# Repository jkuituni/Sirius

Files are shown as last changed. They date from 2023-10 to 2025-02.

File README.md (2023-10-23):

A very simple 6502 based single board computer with just about as much chips as is needed as minimum.

- 6502 CPU
- 8kB EPROM for Firmware
- Up to 48kB RAM comprised from maximum of 6x 8kB SRAM chips
- 8kB reserved I/O area with 1kB blocks having the following;
  - 6551 ACIA for rs232 with max233 level translator
- Two TTL decoder chips for memory mapping.

Initial design of this board was drawn by hand to pieces of paper some 25+ years ago. What you see here is 
an attempt to capture that design into digital form using KiCAD with intentionally not making changes to it if possible.

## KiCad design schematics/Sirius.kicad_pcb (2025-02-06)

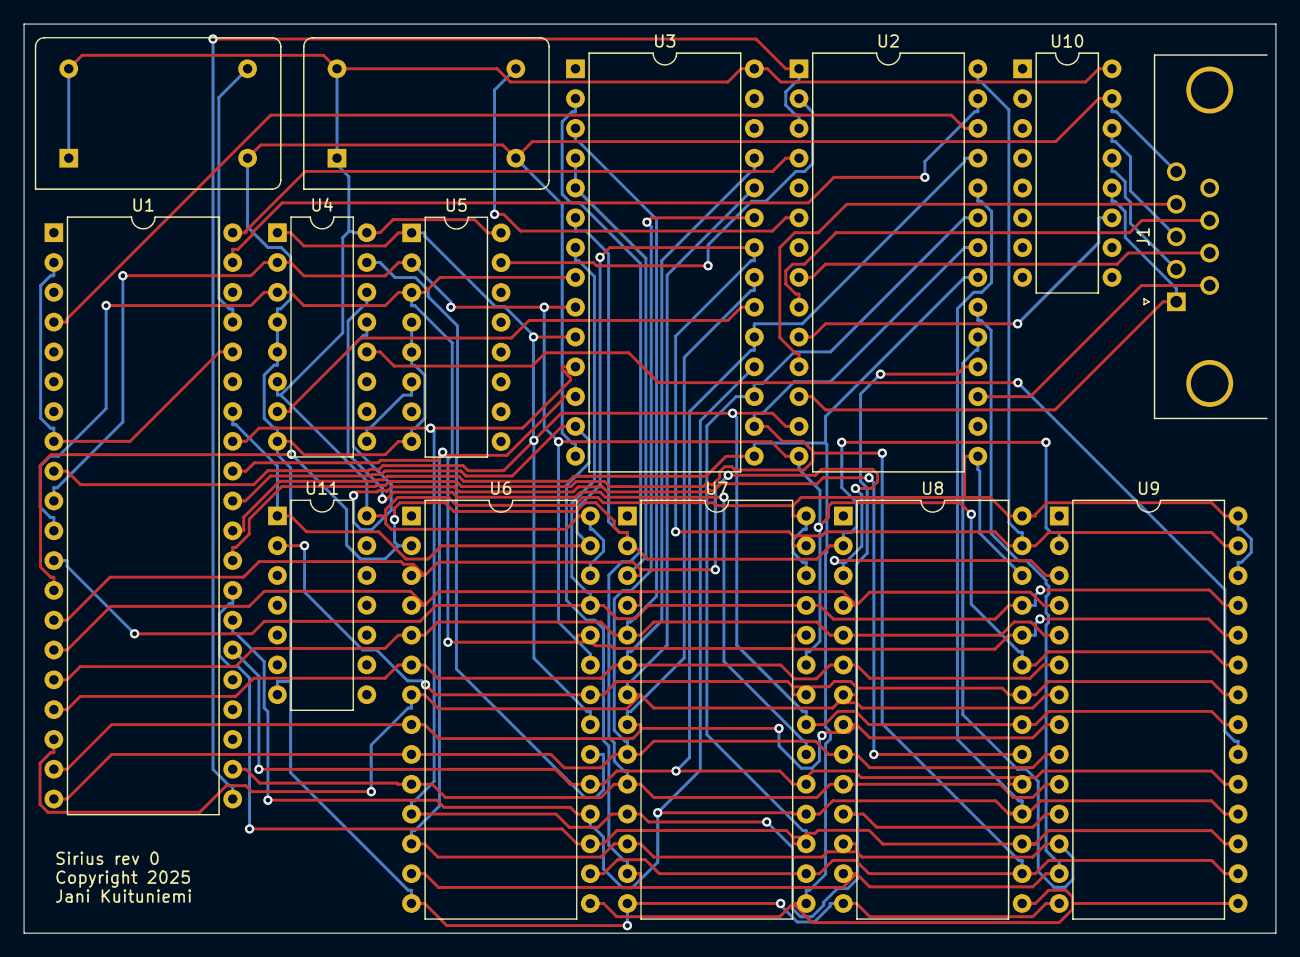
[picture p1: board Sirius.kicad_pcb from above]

Board: 2 copper layers, 106.7 x 77.5 mm, 14 parts (0 on the bottom side), 47 nets.

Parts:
J1: DE9_Plug; DSUB-9_Male_Horizontal_P2.77x2.84mm_EdgePinOffset4.94mm_Hou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
U1: W65C02SxP; DIP-40_W15.24mm
U2: W65C51NxP; DIP-28_W15.24mm
U3: 2764; DIP-28_W15.24mm
U4, U5: 74LS138; DIP-16_W7.62mm
U6, U7, U8, U9: DIP-28_W15.24mm
U10: MAX232; DIP-16_W7.62mm
U11: 7404; DIP-14_W7.62mm
X1, X2: TFT680; Oscillator_DIP-14

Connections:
/D0: U1.33 (D0), U2.18 (D0), U3.11 (D0), U6.11 (I/O0), U7.11 (I/O0), U8.11 (I/O0), U9.11 (I/O0)
/D1: U1.32 (D1), U2.19 (D1), U3.12 (D1), U6.12 (I/O1), U7.12 (I/O1), U8.12 (I/O1), U9.12 (I/O1)
/D2: U1.31 (D2), U2.20 (D2), U3.13 (D2), U6.13 (I/O2), U7.13 (I/O2), U8.13 (I/O2), U9.13 (I/O2)
/D3: U1.30 (D3), U2.21 (D3), U3.15 (D3), U6.15 (I/O3), U7.15 (I/O3), U8.15 (I/O3), U9.15 (I/O3)
/D4: U1.29 (D4), U2.22 (D4), U3.16 (D4), U6.16 (I/O4), U7.16 (I/O4), U8.16 (I/O4), U9.16 (I/O4)
/D5: U1.28 (D5), U2.23 (D5), U3.17 (D5), U6.17 (I/O5), U7.17 (I/O5), U8.17 (I/O5), U9.17 (I/O5)
/D6: U1.27 (D6), U2.24 (D6), U3.18 (D6), U6.18 (I/O6), U7.18 (I/O6), U8.18 (I/O6), U9.18 (I/O6)
/D7: U1.26 (D7), U2.25 (D7), U3.19 (D7), U6.19 (I/O7), U7.19 (I/O7), U8.19 (I/O7), U9.19 (I/O7)
A0: U1.9 (A0), U2.13 (RS0), U3.10 (A0), U4.1 (A0), U5.1 (A0), U6.21 (A0), U7.21 (A0), U8.21 (A0), U9.21 (A0)
A1: U1.10 (A1), U2.14 (RS1), U3.9 (A1), U4.2 (A1), U5.2 (A1), U6.23 (A1), U7.23 (A1), U8.23 (A1), U9.23 (A1)
A2: U1.11 (A2), U3.8 (A2), U4.3 (A2), U5.3 (A2), U6.24 (A2), U7.24 (A2), U8.24 (A2), U9.24 (A2)
A3: U1.12 (A3), U3.7 (A3), U6.25 (A3), U7.25 (A3), U8.25 (A3), U9.25 (A3)
A4: U1.13 (A4), U3.6 (A4), U6.2 (A4), U7.2 (A4), U8.2 (A4), U9.2 (A4)
A5: U1.14 (A5), U3.4 (A6), U3.5 (A5), U6.3 (A5), U7.3 (A5), U8.3 (A5), U9.3 (A5)
A6: U1.15 (A6), U6.4 (A6), U7.4 (A6), U8.4 (A6), U9.4 (A6)
A7: U1.16 (A7), U3.3 (A7), U6.5 (A7), U7.5 (A7), U8.5 (A7), U9.5 (A7)
A8: U1.17 (A8), U3.25 (A8), U6.6 (A8), U7.6 (A8), U8.6 (A8), U9.6 (A8)
A9: U1.18 (A9), U3.24 (A9), U6.7 (A9), U7.7 (A9), U8.7 (A9), U9.7 (A9)
A10: U1.19 (A10), U3.21 (A10), U6.8 (A10), U7.8 (A10), U8.8 (A10), U9.8 (A10)
A11: U1.20 (A11), U3.23 (A11), U6.9 (A11), U7.9 (A11), U8.9 (A11), U9.9 (A11)
A12: U1.22 (A12), U3.2 (A12), U6.10 (A12), U7.10 (A12), U8.10 (A12), U9.10 (A12)
GND: J1.5, U3.14 (GND), U4.4 (E1), U4.5 (E2), U4.8 (GND), U5.4 (E1), U5.5 (E2), U5.8 (GND), U6.14 (GND), U7.14 (GND), U8.14 (GND), U9.14 (GND), U10.15 (GND), U11.7 (GND), X1.7 (GND), X2.7 (GND)
unnamed: U1.34 (R/~W), U2.28 (R/~W), U3.22 (~OE), U6.27 (/WE), U7.27 (/WE), U8.27 (/WE), U9.27 (/WE), U11.1
unnamed: U1.4 (~IRQ), U2.26 (~IRQ)
unnamed: U1.40 (~RES), U2.4 (~RES)
unnamed: U1.37 (ϕ0), X1.8 (OUT)
unnamed: U1.39 (ϕ2), U2.27 (ϕ2)
unnamed: U2.2 (CS1), U5.15 (O0)
unnamed: U2.6 (XTAL1), X2.8 (OUT)
unnamed: J1.8, U2.9 (~CTS)
unnamed: J1.6, U2.17 (~DSR)
unnamed: J1.4, U2.11 (~DTR)
unnamed: J1.7, U2.8 (~RTS)
unnamed: U3.20 (~CE), U4.7 (O7)
unnamed: U4.15 (O0), U6.20 (/CE1)
unnamed: U4.14 (O1), U7.20 (/CE1)
unnamed: U4.13 (O2), U8.20 (/CE1)
unnamed: U4.12 (O3), U9.20 (/CE1)
unnamed: U4.9 (O6), U5.6 (E3)
unnamed: U6.22 (/OE), U7.22 (/OE), U8.22 (/OE), U9.22 (/OE), U11.2
unnamed: J1.2, U10.13 (R1IN)
unnamed: J1.1, U2.12 (RxD), U2.16 (~DCD), U10.12 (R1OUT)
unnamed: U2.10 (TxD), U10.11 (T1IN)
unnamed: J1.3, U10.14 (T1OUT)
VCC: U2.15 (VCC), U3.28 (VCC), U4.6 (E3), U4.16 (VCC), U5.16 (VCC), U6.26 (CE2), U6.28 (Vcc), U7.26 (CE2), U7.28 (Vcc), U8.26 (CE2), U8.28 (Vcc), U9.26 (CE2), U9.28 (Vcc), U10.16 (VCC), U11.14 (VCC), X1.1 (EN), X1.14 (Vcc), X2.1 (EN), X2.14 (Vcc)
VDD: U1.2 (RDY), U1.8 (VDD), U1.36 (BE)
VSS: U1.21 (VSS), U2.1 (VSS), U2.3 (~CS2)

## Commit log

2023-10-23 Initial commit with very much incomplete work-in-progress schematics.
    [Sirius.kicad_pcb, Sirius.kicad_sch]
2023-10-23 Re-worked schematics. Still lot of work to be done.
    [Sirius.kicad_sch]
2023-10-24 Added RAM along with connectivity. Still issues with using the Bus.
    [Sirius.kicad_pcb, Sirius.kicad_sch]
2023-10-24 Added rs232 parts. Still some caps to add.
    [Sirius.kicad_pcb, Sirius.kicad_sch]
2023-10-24 Added N/C (No Connect) flags.
    [Sirius.kicad_sch]
2023-10-24 Added some more signal handling and caps for rs232 infterface's max232 level shifter.
    [Sirius.kicad_sch]
2023-10-24 Minor tweaks to signals and PCB layout.
    [Sirius.kicad_pcb, Sirius.kicad_sch]
2024-02-22 Fixed the Bus connetions. Added a forgotten 7404 inverter for R/W signal and did a autorouted board.
    [Sirius.kicad_pcb, Sirius.kicad_sch]
2025-01-19 Minor alterations to PCB layout.
    [Sirius.kicad_pcb, Sirius.kicad_sch]
2025-02-06 Some ERC and DRC fixes.
    [Sirius.kicad_pcb]

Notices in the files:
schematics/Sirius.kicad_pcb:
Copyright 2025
